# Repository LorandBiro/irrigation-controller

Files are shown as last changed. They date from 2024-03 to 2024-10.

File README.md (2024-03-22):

# Irrigation Controller

This repository contains the software, hardware design, and documentation of a smart irrigation controller. The system is designed and created for personal use.

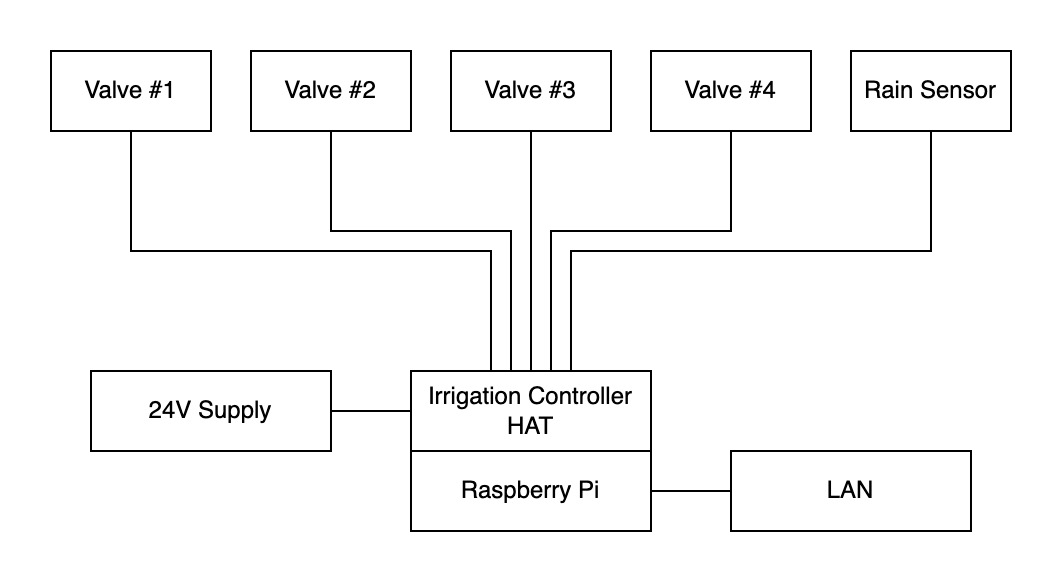
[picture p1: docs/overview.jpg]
Overview


## Features
- Automated irrigation using 4 solenoid valves.
- Configuration and control through web interface.
- Suspension of irrigation when it's raining.
- Short-circuit detection.
- DIN rail mounting.

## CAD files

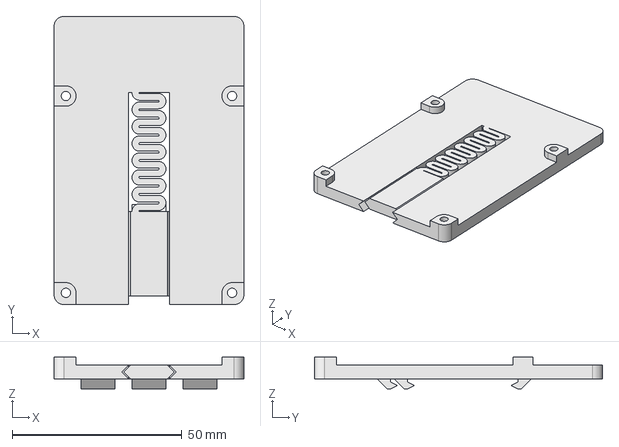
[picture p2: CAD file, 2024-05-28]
mount/Mount.FCStd
56.0 x 85.0 x 9.40 mm

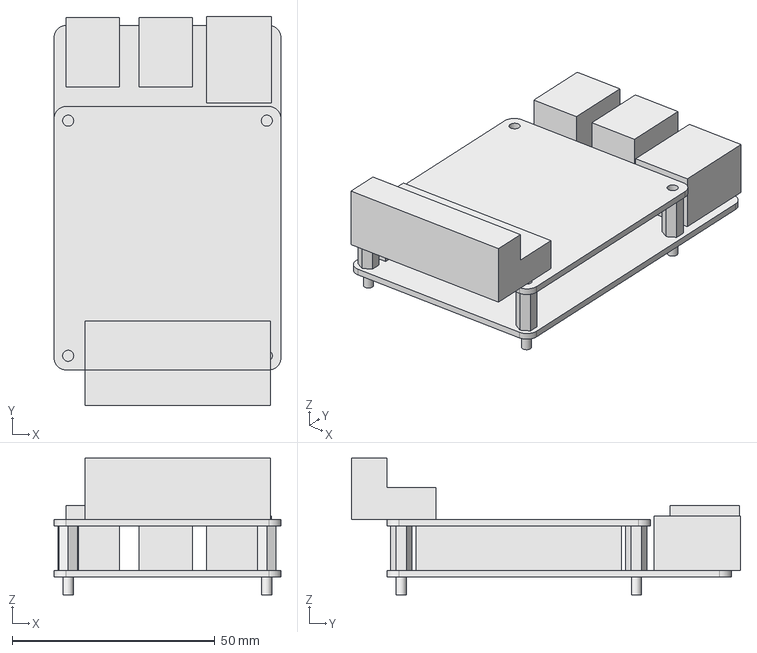
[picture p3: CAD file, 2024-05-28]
mount/RaspberryPi.FCStd
56.0 x 96.0 x 33.7 mm

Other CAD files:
mount/Assembly.FCStd

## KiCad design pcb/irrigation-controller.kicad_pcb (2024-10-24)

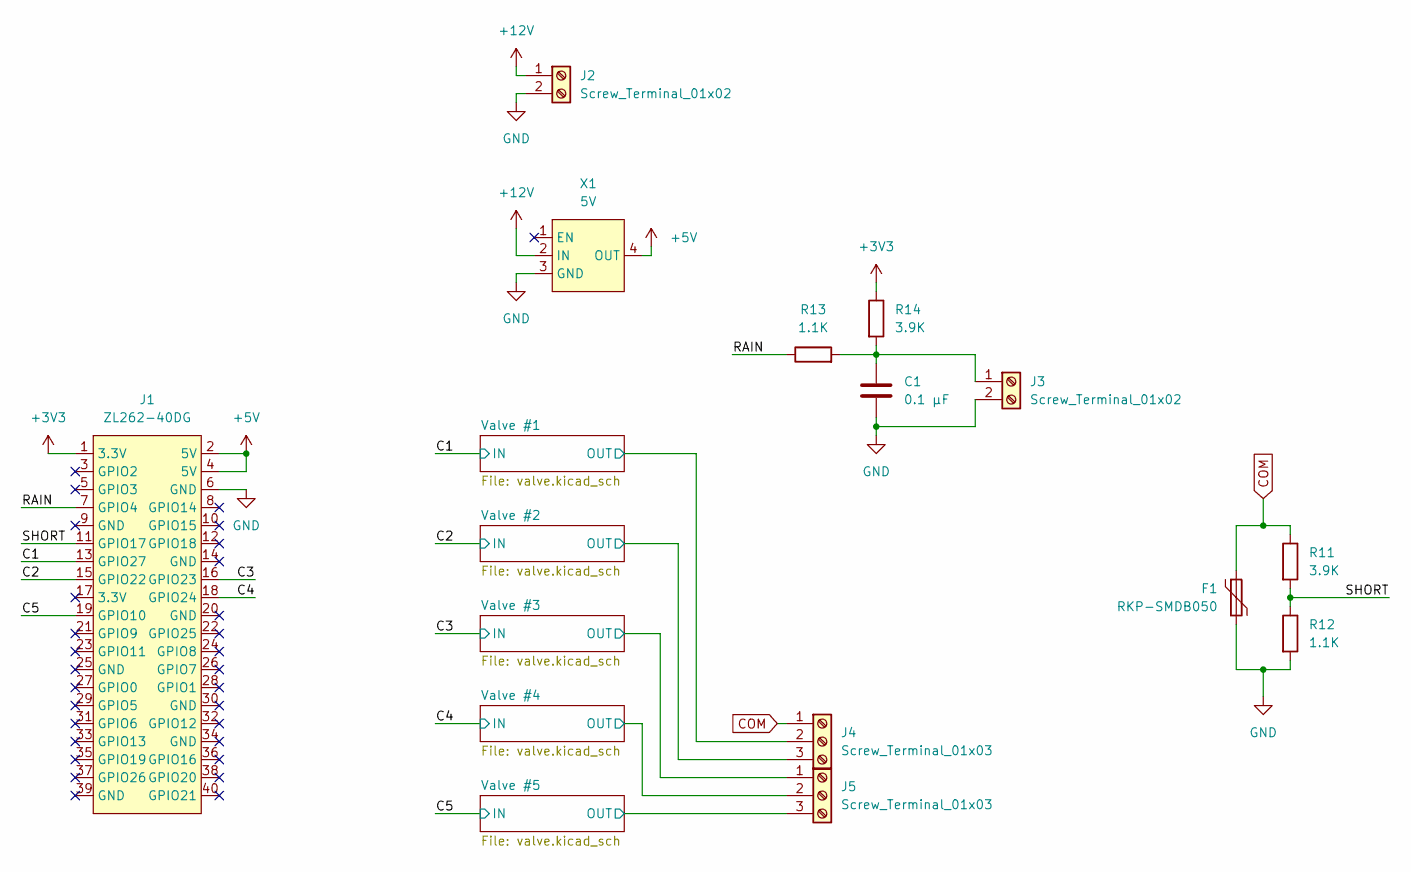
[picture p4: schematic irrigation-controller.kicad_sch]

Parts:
C1: 0.1 µF; C_0805_2012Metric
F1: RKP-SMDB050; Fuse_1206_3216Metric
J1: ZL262-40DG; PinSocket_2x20_P2.54mm_Vertical
J2, J3: Screw_Terminal_01x02; MX5-2P-BK
J4, J5: Screw_Terminal_01x03; MX5-3P-BK
R11, R14: 3.9K; R_0805_2012Metric
R12, R13: 1.1K; R_0805_2012Metric
X1: 5V; STDN-3A24-ADJ

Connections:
+3V3: J1.1 (3.3V), R14.1
+5V: J1.2 (5V), J1.4 (5V), X1.4 (OUT)
+12V: J2.1, X1.2 (IN); also elsewhere on the board
/C1: J1.13 (GPIO27); also elsewhere on the board
/C2: J1.15 (GPIO22); also elsewhere on the board
/C3: J1.16 (GPIO23); also elsewhere on the board
/C4: J1.18 (GPIO24); also elsewhere on the board
/C5: J1.19 (GPIO10); also elsewhere on the board
/RAIN: J1.7 (GPIO4), R13.1
/SHORT: J1.11 (GPIO17), R11.2, R12.1
/Valve #1/OUT: J4.2; also elsewhere on the board
/Valve #2/OUT: J4.3; also elsewhere on the board
/Valve #3/OUT: J5.1; also elsewhere on the board
/Valve #4/OUT: J5.2; also elsewhere on the board
/Valve #5/OUT: J5.3; also elsewhere on the board
COM: F1.1, J4.1, R11.1; also elsewhere on the board
GND: C1.2, F1.2, J1.6 (GND), J2.2, J3.2, R12.2, X1.3 (GND); also elsewhere on the board
unnamed: C1.1, J3.1, R13.2, R14.2

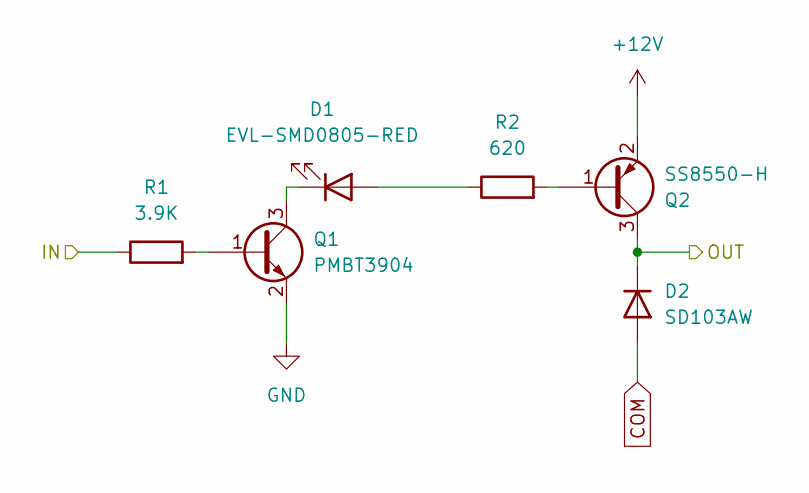
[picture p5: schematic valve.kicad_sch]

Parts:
D1: EVL-SMD0805-RED; LED_0805_2012Metric_Pad1.15x1.40mm_HandSolder
D2: SD103AW; D_SOD-123
Q1: PMBT3904; TSOT-23
Q2: SS8550-H; TSOT-23
R1: 3.9K; R_0805_2012Metric_Pad1.20x1.40mm_HandSolder
R2: 620; R_0805_2012Metric

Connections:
+12V: Q2.2 (E); also elsewhere on the board
/C1: R1.1; also elsewhere on the board
/Valve #1/OUT: D2.1 (K), Q2.3 (C); also elsewhere on the board
COM: D2.2 (A); also elsewhere on the board
GND: Q1.2 (E); also elsewhere on the board
unnamed: D1.2 (A), R2.1
unnamed: D1.1 (K), Q1.3 (C)
unnamed: Q1.1 (B), R1.2
unnamed: Q2.1 (B), R2.2

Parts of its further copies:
D3, D5, D7, D9: EVL-SMD0805-RED; LED_0805_2012Metric_Pad1.15x1.40mm_HandSolder
D4, D6, D8, D10: SD103AW; D_SOD-123
Q3, Q5, Q7, Q9: PMBT3904; TSOT-23
Q4, Q6, Q8, Q10: SS8550-H; TSOT-23
R3, R5, R7, R9: 3.9K; R_0805_2012Metric_Pad1.20x1.40mm_HandSolder
R4, R6, R8, R10: 620; R_0805_2012Metric

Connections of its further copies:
+12V: Q4.2 (E), Q6.2 (E), Q8.2 (E), Q10.2 (E); also elsewhere on the board
/C2: R3.1; also elsewhere on the board
/C3: R5.1; also elsewhere on the board
/C4: R7.1; also elsewhere on the board
/C5: R9.1; also elsewhere on the board
/Valve #2/OUT: D4.1 (K), Q4.3 (C); also elsewhere on the board
/Valve #3/OUT: D6.1 (K), Q6.3 (C); also elsewhere on the board
/Valve #4/OUT: D8.1 (K), Q8.3 (C); also elsewhere on the board
/Valve #5/OUT: D10.1 (K), Q10.3 (C); also elsewhere on the board
COM: D4.2 (A), D6.2 (A), D8.2 (A), D10.2 (A); also elsewhere on the board
GND: Q3.2 (E), Q5.2 (E), Q7.2 (E), Q9.2 (E); also elsewhere on the board
unnamed: D3.2 (A), R4.1
unnamed: D3.1 (K), Q3.3 (C)
unnamed: D5.2 (A), R6.1
unnamed: D5.1 (K), Q5.3 (C)
unnamed: D7.2 (A), R8.1
unnamed: D7.1 (K), Q7.3 (C)
unnamed: D9.2 (A), R10.1
unnamed: D9.1 (K), Q9.3 (C)
unnamed: Q3.1 (B), R3.2
unnamed: Q4.1 (B), R4.2
unnamed: Q5.1 (B), R5.2
unnamed: Q6.1 (B), R6.2
unnamed: Q7.1 (B), R7.2
unnamed: Q8.1 (B), R8.2
unnamed: Q9.1 (B), R9.2
unnamed: Q10.1 (B), R10.2

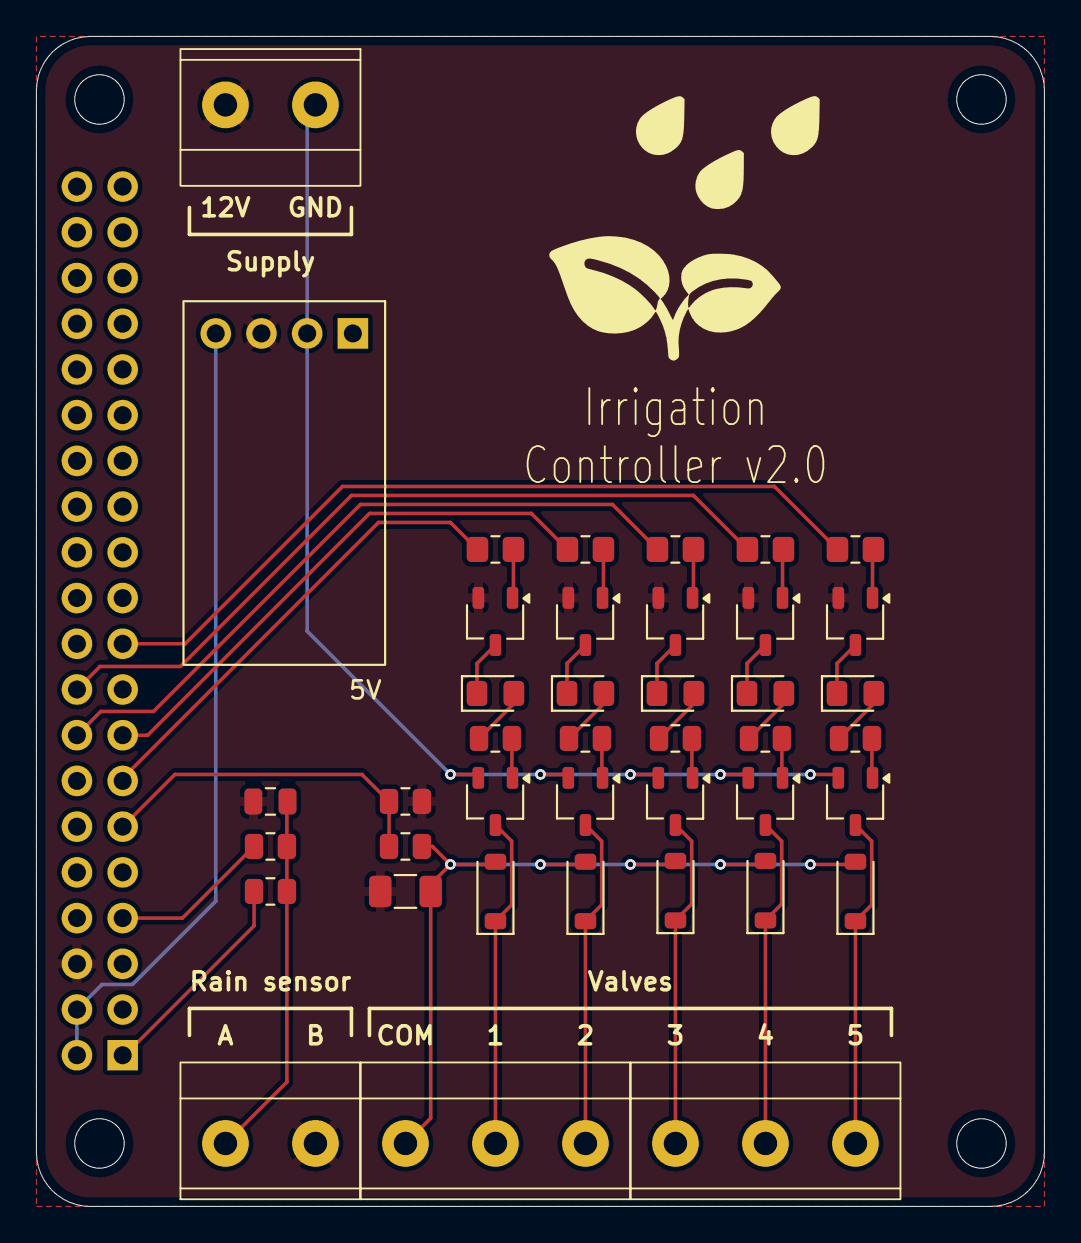
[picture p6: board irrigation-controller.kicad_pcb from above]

Board: 2 copper layers, 56.0 x 65.0 mm, 42 parts (1 on the bottom side), 38 nets.

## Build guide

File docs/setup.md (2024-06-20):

# Raspberry Pi setup

Use Raspberry Pi Imager to burn Raspberry Pi OS Lite (64-bit).
- Configure wifi
- Enable ssh
- Set username: lbiro
- Set the hostname: irrigation
- Configure localization

Install git, clone the repository and run `setup.sh`.

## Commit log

2024-03-22 Add PCB design
    [irrigation-controller.kicad_pcb, irrigation-controller.kicad_sch, valve.kicad_sch]
2024-04-03 Update resistor values based on availability
    [irrigation-controller.kicad_sch, valve.kicad_sch]
2024-04-26 Add DIN rail mounting clip
    [Assembly.FCStd, Base.FCStd, RaspberryPi.FCStd]
2024-05-28 Update mount design
    The first version's spring is too weak and the device is very loose on
    the DIN rail. The spring thickness was increased and the slider position
    is modified so the spring will be under tension when it's on the DIN
    rail. Hopefully this tension will make the device more stable.
    [Assembly.FCStd, Base.FCStd]
2024-06-12 Add basic web app: valves can be opened and closed manually
2024-06-13 Add valve names
2024-06-13 Add valve delay
2024-06-13 Close valves on startup
2024-06-15 Open/close valves with the same button
2024-06-15 Move ValveConfig to Domain
2024-06-15 Add Step and Stop buttons
2024-06-15 Move valve control to a component
2024-06-15 Add rain sensor
2024-06-15 Add short circuit sensor
2024-06-16 Log short circuit clear
2024-06-16 Add ValveRepository, store IsDefective, guard against opening defective valves
2024-06-16 Disable defective valve buttons
2024-06-16 Add fix valve button
2024-06-16 Simplify manual program and disable defective valves
2024-06-20 Add scripts for raspberry pi
2024-06-21 Add open zone and short circuit to Prometheus
2024-06-22 Add temperature data
2024-08-31 Change OpenMeteoApi logging to trace
2024-10-24 Change terminal, add another output, add hardware debouncing
    [irrigation-controller.kicad_pcb, irrigation-controller.kicad_sch, valve.kicad_sch]
2024-10-24 Adjust components based on availability
    [irrigation-controller.kicad_sch, valve.kicad_sch]
2024-11-02 Skip irrigation if temperature is too low
